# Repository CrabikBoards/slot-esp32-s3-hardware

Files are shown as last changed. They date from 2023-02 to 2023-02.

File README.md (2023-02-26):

# Crabik Slot ESP32-S3 Hardware

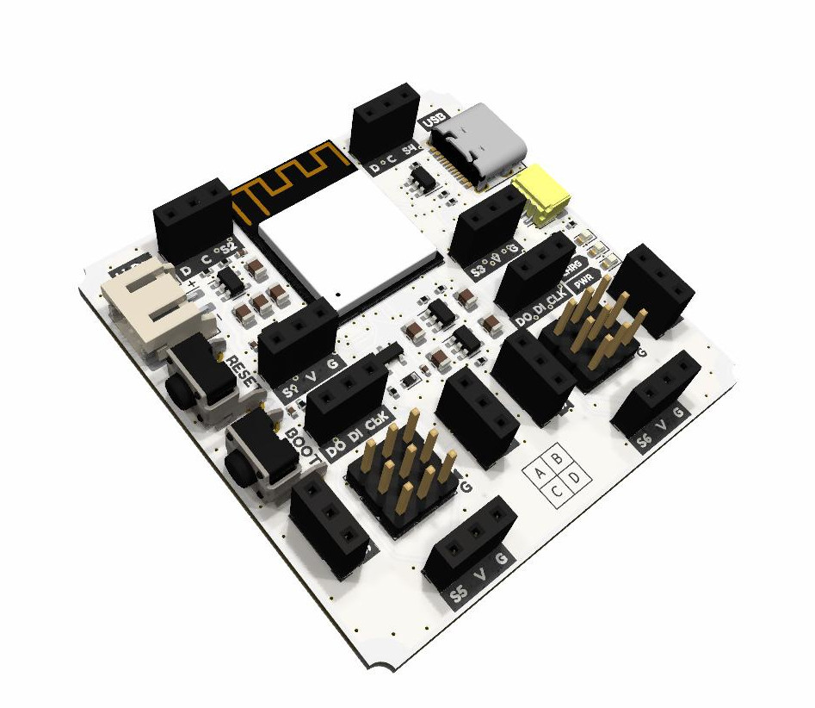
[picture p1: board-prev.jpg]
Board prev


Crabik Slot was created so that you can quickly prototype, research and educational projects, because it makes it easy to create and test without having to assemble everything on a breadboard and dig into a pile of wires.

Schematics and board designs (KiCad projects), distributed as open hardware and available under CERN-OHL-W v2 license.

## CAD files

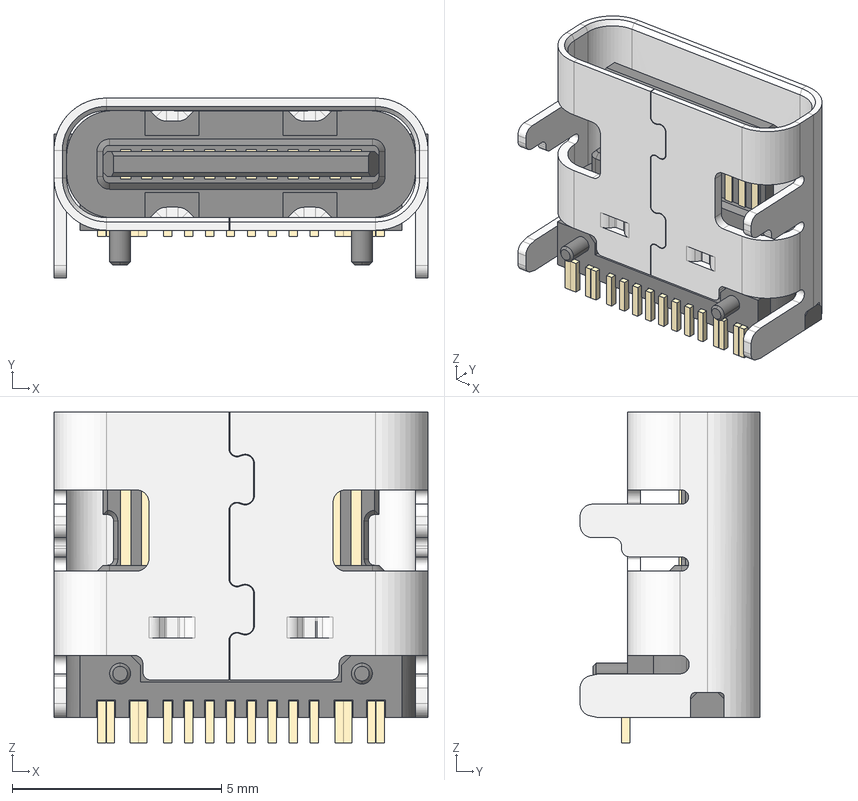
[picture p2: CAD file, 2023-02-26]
3d/TYPE-C-31-M-12.step
8.94 x 4.30 x 7.90 mm

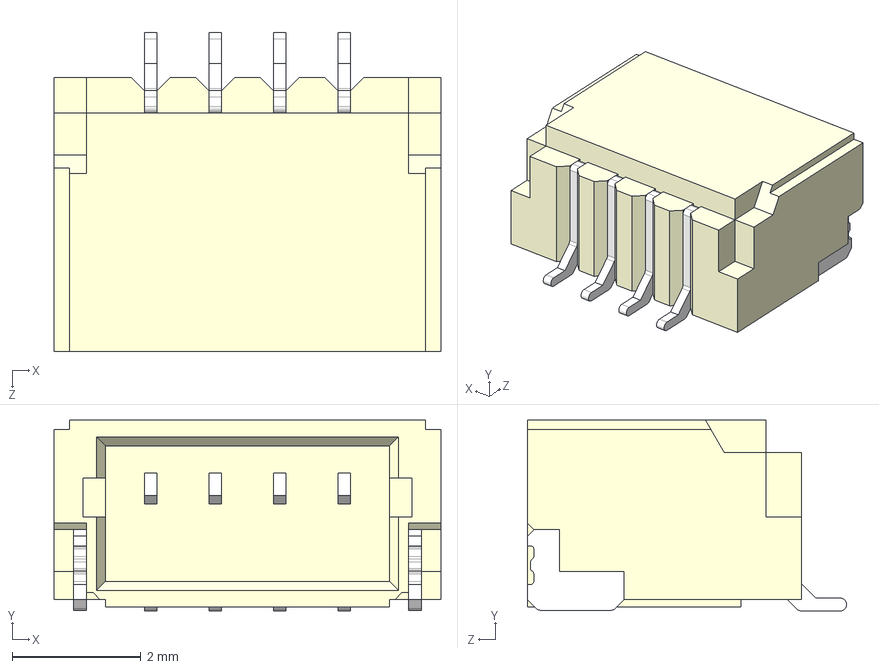
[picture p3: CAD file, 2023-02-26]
3d/JST_SH_SM04B-SRSS-TB_1x04-1MP_P1.00mm_Horizontal.STEP
6.00 x 2.96 x 4.95 mm

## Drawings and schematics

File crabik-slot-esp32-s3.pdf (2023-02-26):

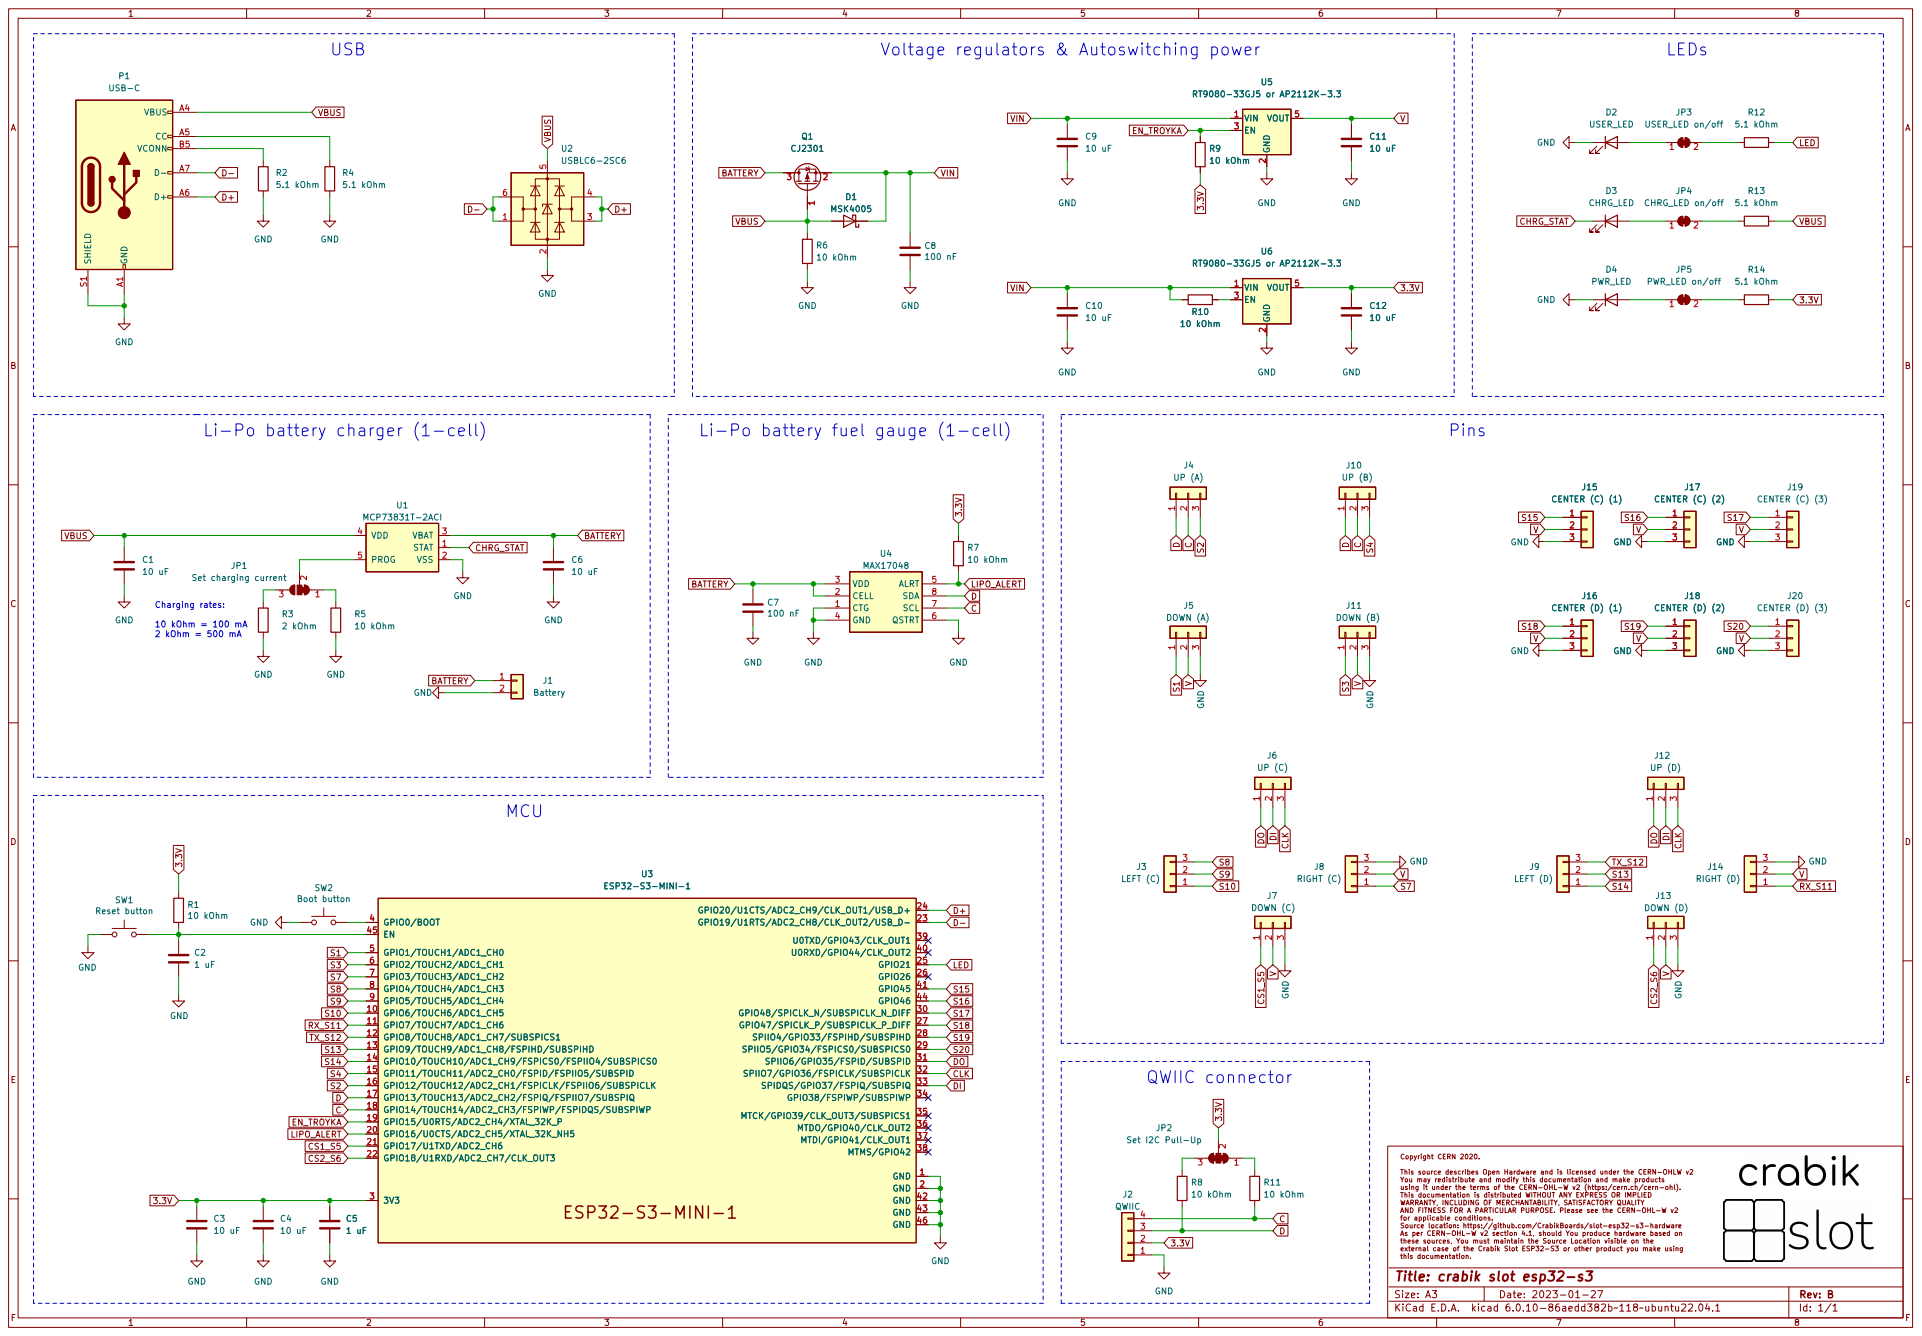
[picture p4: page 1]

Li-Po battery charger (1-cell)
10 uF GND

JP1 Set charging current GND GND

Charging rates: 10 kOhm = 100 mA

JP2 Set I2C Pull-Up GND

This source describes Open Hardware and is licensed under the CERN-OHLW v2

You may redistribute and modify this documentation and make products

using it under the terms of the CERN-OHL-W v2 (https:/cern.ch/cern-ohl).

Id: 1/1 Title: crabik slot esp32-s3

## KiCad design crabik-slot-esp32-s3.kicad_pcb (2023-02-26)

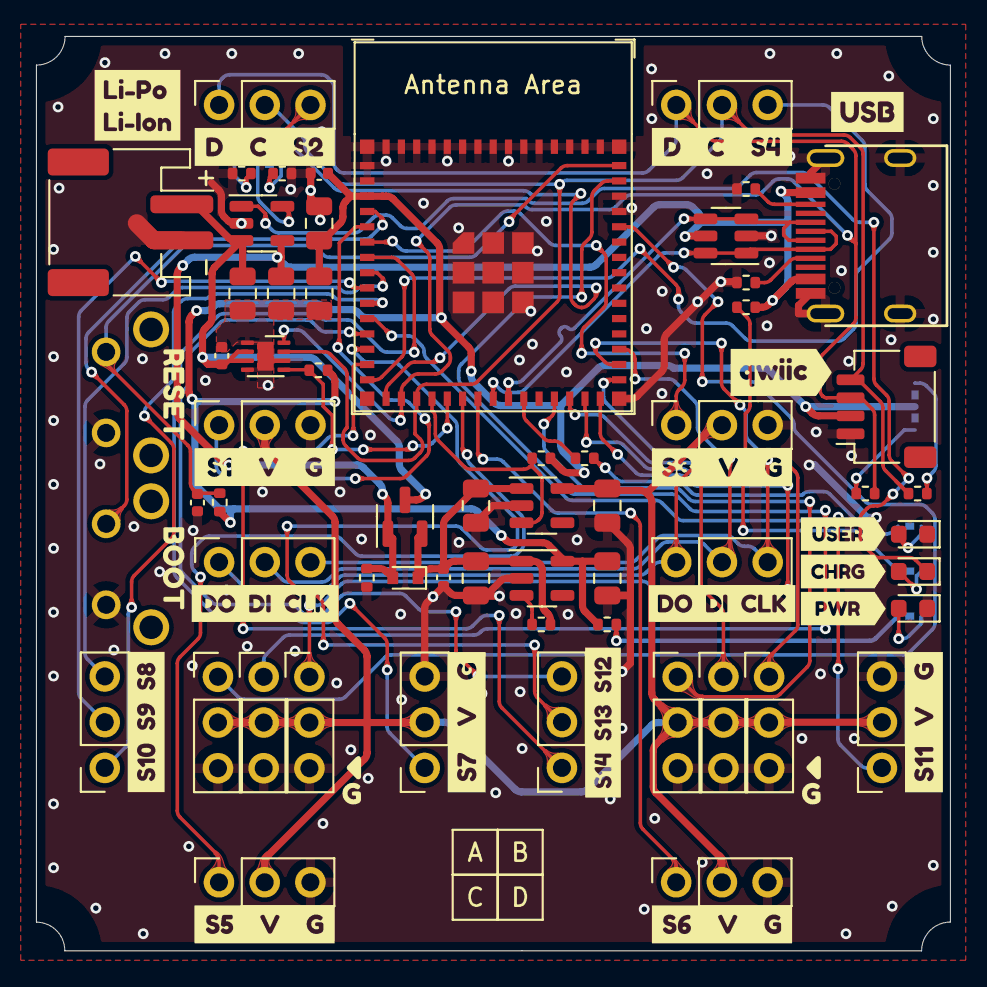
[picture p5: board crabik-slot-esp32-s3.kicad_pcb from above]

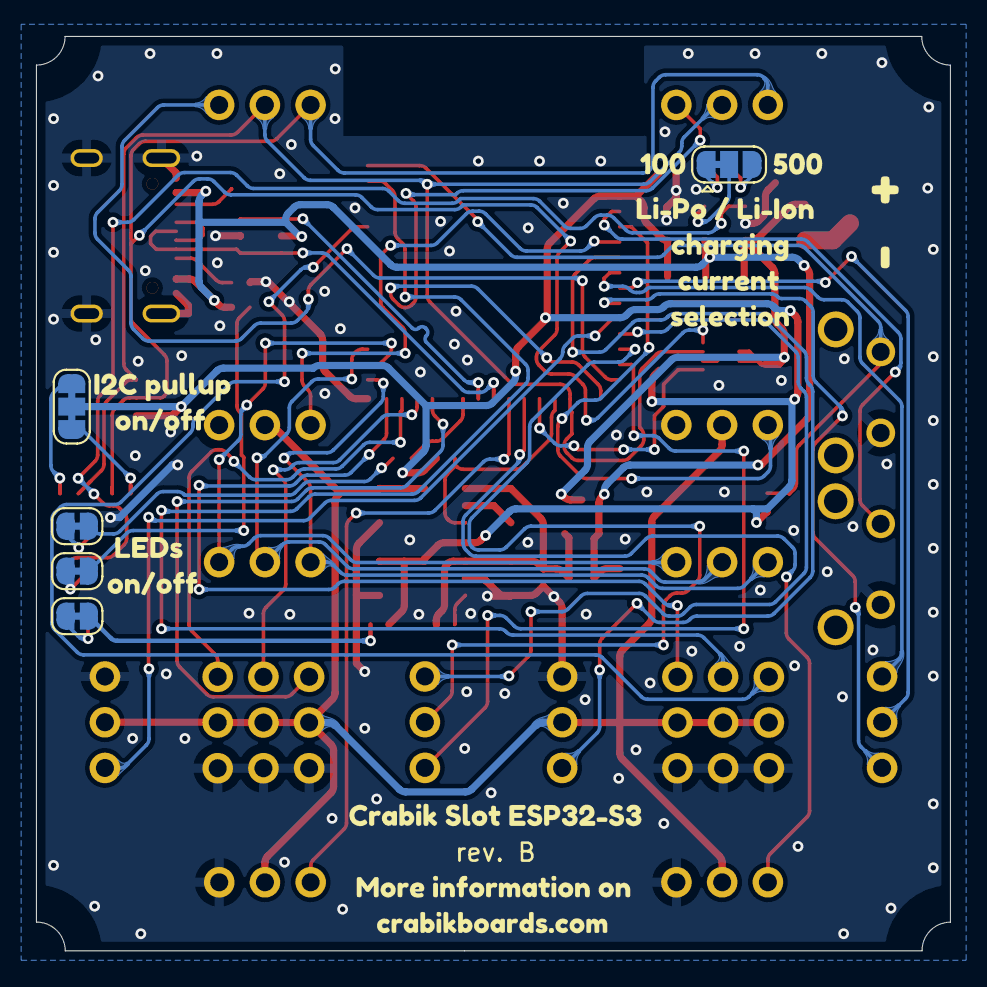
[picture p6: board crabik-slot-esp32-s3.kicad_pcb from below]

Board: 2 copper layers, 50.8 x 50.8 mm, 95 parts (13 on the bottom side), 53 nets.

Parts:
C1, C3, C4#2, C6, C9, C10, C11, C12: 10 uF; C_0805_2012Metric
C2, C5: 1 uF; C_0402_1005Metric
C4, C4#3: 100nF; C_0402_1005Metric
D1: MSK4005; D_SOD-523
D2: USER_LED; LED_0603_1608Metric
D3: CHRG_LED; LED_0603_1608Metric
D4: PWR_LED; LED_0603_1608Metric
J1, J1#2, J1#3, J1#4, J1#5, J1#7: UP (A); PinSocket_1x03_P2.54mm_Vertical
J1#6: Battery; JST_PH_S2B-PH-SM4-TB_1x02-1MP_P2.00mm_Horizontal
J2, J2#3: DOWN (A); PinSocket_1x03_P2.54mm_Vertical
J2#2: QWIIC; JST_SH_SM04B-SRSS-TB_1x04-1MP_P1.00mm_Horizontal
J4, J4#2: UP (B); PinSocket_1x03_P2.54mm_Vertical
J5, J5#2: DOWN (B); PinSocket_1x03_P2.54mm_Vertical
J15: CENTER (C) (1); PinHeader_1x03_P2.54mm_Vertical
J16: CENTER (D) (1); PinHeader_1x03_P2.54mm_Vertical
J17: CENTER (C) (2); PinHeader_1x03_P2.54mm_Vertical
J18: CENTER (D) (2); PinHeader_1x03_P2.54mm_Vertical
J19: CENTER (C) (3); PinHeader_1x03_P2.54mm_Vertical
J20: CENTER (D) (3); PinHeader_1x03_P2.54mm_Vertical
JP1: Set charging current; SolderJumper-3_P1.3mm_Bridged12_RoundedPad1.0x1.5mm
JP2: Set I2C Pull-Up; SolderJumper-3_P1.3mm_Bridged12_RoundedPad1.0x1.5mm_копия
JP3: USER_LED on/off; SolderJumper-2_P1.3mm_Bridged_RoundedPad1.0x1.5mm
JP4: CHRG_LED on/off; SolderJumper-2_P1.3mm_Bridged_RoundedPad1.0x1.5mm
JP5: PWR_LED on/off; SolderJumper-2_P1.3mm_Bridged_RoundedPad1.0x1.5mm
P1: USB-C; TYPE-C16PIN
Q1: CJ2301; SOT-23
R1: 10k; R_0402_1005Metric
R2, R4, R12, R13, R14: 5.1 kOhm; R_0402_1005Metric
R3: 2 kOhm; R_0402_1005Metric
R5, R6, R7, R8, R9, R10, R11: 10 kOhm; R_0402_1005Metric
SW1, SW1#2: Reset button; KEY-TH_4P-L7.1-W5.0-P4.50-LS2.5
U1: MCP73831T-2ACI; SOT-23-5
U2: USBLC6-2SC6; SOT-23-6
U3: ESP32-S3-MINI-1
U4: MAX17048; DFN-8-1EP_2x2mm_P0.5mm_EP0.9x1.6mm
U5, U6: RT9080-33GJ5 or AP2112K-3.3; SOT-23-5
kibuzzard-63C28F32: G***; kibuzzard-63C28F32
kibuzzard-63C28786: G***; kibuzzard-63C28786
kibuzzard-63C28790: G***; kibuzzard-63C28790
kibuzzard-63CA6CBF: G***; kibuzzard-63CA6CBF
kibuzzard-63CA6FA5: G***; kibuzzard-63CA6FA5
kibuzzard-63CE9BA7: G***; kibuzzard-63CE9BA7
kibuzzard-63CFAB7C: G***; kibuzzard-63CFAB7C
kibuzzard-63CFAB43: G***; kibuzzard-63CFAB43
kibuzzard-63CFACF8: G***; kibuzzard-63CFACF8
kibuzzard-63CFADAC: G***; kibuzzard-63CFADAC
kibuzzard-63CFAED5: G***; kibuzzard-63CFAED5
kibuzzard-63CFAF5C: G***; kibuzzard-63CFAF5C
kibuzzard-63CFAFAA: G***; kibuzzard-63CFAFAA
kibuzzard-63CFAFDE: G***; kibuzzard-63CFAFDE
kibuzzard-63CFB1DC: G***; kibuzzard-63CFB1DC
kibuzzard-63CFB14C, kibuzzard-63CFB14C#2: G***; kibuzzard-63CFB14C
kibuzzard-63CFB240: G***; kibuzzard-63CFB240
kibuzzard-63CFBBB1, kibuzzard-63CFBBB1#2: G***; kibuzzard-63CFBBB1
kibuzzard-637DF95D: G***; kibuzzard-637DF95D
kibuzzard-637DF950: G***; kibuzzard-637DF950
kibuzzard-637DF968: G***; kibuzzard-637DF968
kibuzzard-637F6C97: G***; kibuzzard-637F6C97
kibuzzard-637F6D25: G***; kibuzzard-637F6D25
kibuzzard-637F6DEA: G***; kibuzzard-637F6DEA
kibuzzard-637F6E06: G***; kibuzzard-637F6E06
kibuzzard-637F66BD: G***; kibuzzard-637F66BD
kibuzzard-637F708F: G***; kibuzzard-637F708F
kibuzzard-637F7041: G***; kibuzzard-637F7041

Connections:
3.3V: C3.1, C4#2.1, C5.1, C12.1, J2#2.2, JP2.2 (C), R1.1, R7.1, R9.2, R14.2, U3.3 (3V3), U6.5 (VOUT)
BATTERY: C4#3.1, C6.1, J1#6.1, Q1.3 (D), U1.3 (VBAT), U4.2 (CELL), U4.3 (VDD)
C: J1.2, J2#2.4, J4#2.2, R11.2, U3.18 (GPIO14/TOUCH14/ADC2_CH3/FSPIWP/FSPIDQS/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), U4.7 (SCL)
CHRG_STAT: D3.1 (K), U1.1 (STAT)
CLK: J1#4.3, J4.3, U3.32 (SPIIO7/GPIO36/FSPICLK/SUBSPICLK)
CS1_S5: J2#3.1, U3.21 (GPIO17/U1TXD/ADC2_CH6)
CS2_S6: J5#2.1, U3.22 (GPIO18/U1RXD/ADC2_CH7/CLK_OUT3)
D: J1.1, J2#2.3, J4#2.1, R8.2, U3.17 (GPIO13/TOUCH13/ADC2_CH2/FSPIQ/FSPIIO7/S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), U4.8 (SDA)
D+: P1.A6 (D+), U2.3 (I/O2), U2.4 (I/O2), U3.24 (GPIO20/U1CTS/ADC2_CH9/CLK_OUT1/USB_D+)
D-: P1.A7 (D-), U2.1 (I/O1), U2.6 (I/O1), U3.23 (GPIO19/U1RTS/ADC2_CH8/CLK_OUT2/USB_D-)
DI: J1#4.2, J4.2, U3.33 (SPIDQS/GPIO37/FSPIQ/SUBSPIQ)
DO: J1#4.1, J4.1, U3.31 (SPIIO6/GPIO35/FSPID/SUBSPID)
EN_TROYKA: R9.1, U3.19 (GPIO15/U0RTS/ADC2_CH4/XTAL_32K_P), U5.3 (EN)
GND: C1.2, C2.2, C3.2, C4.2, C4#2.2, C4#3.2, C5.2, C6.2, C9.2, C10.2, C11.2, C12.2, D2.1 (K), D4.1 (K), J1#2.3, J1#6.2, J1#7.3, J2.3, J2#2.1, J2#3.3, J5.3, J5#2.3, J15.3, J16.3, J17.3, J18.3, J19.3, J20.3, P1.A1 (GND), P1.S1 (SHIELD), R2.2, R3.2, R4.2, R5.2, R6.2, SW1.2, SW1#2.2, U1.2 (VSS), U2.2 (GND), U3.1 (GND), U3.2 (GND), U3.42 (GND), U3.43 (GND), U3.46 (GND), U4.1 (CTG), U4.4 (GND), U4.6 (QSTRT), U4.9 (GND), U5.2 (GND), U6.2 (GND)
LED: R12.2, U3.25 (GPIO21)
LIPO_ALERT: R7.2, U3.20 (GPIO16/U0CTS/ADC2_CH5/XTAL_32K_NH5), U4.5 (ALRT)
unnamed: C2.1, R1.2, SW1#2.1, U3.45 (EN)
unnamed: D2.2 (A), JP3.1 (A)
unnamed: D3.2 (A), JP4.1 (A)
unnamed: D4.2 (A), JP5.1 (A)
unnamed: JP1.1 (A), R5.1
unnamed: JP1.2 (C), U1.5 (PROG)
unnamed: JP1.3 (B), R3.1
unnamed: JP2.1 (A), R11.1
unnamed: JP2.3 (B), R8.1
unnamed: JP3.2 (B), R12.1
unnamed: JP4.2 (B), R13.1
unnamed: JP5.2 (B), R14.1
unnamed: P1.A5 (CC), R4.1
unnamed: P1.B5 (VCONN), R2.1
unnamed: R10.2, U6.3 (EN)
unnamed: SW1.1, U3.4 (GPIO0/BOOT)
RX_S11: J1#2.1, U3.11 (GPIO7/TOUCH7/ADC1_CH6)
S1: J2.1, U3.5 (GPIO1/TOUCH1/ADC1_CH0)
S2: J1.3, U3.16 (GPIO12/TOUCH12/ADC2_CH1/FSPICLK/FSPIIO6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)
S3: J5.1, U3.6 (GPIO2/TOUCH2/ADC1_CH1)
S4: J4#2.3, U3.15 (GPIO11/TOUCH11/ADC2_CH0/FSPID/FSPIIO5/S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)
S7: J1#7.1, U3.7 (GPIO3/TOUCH3/ADC1_CH2)
S8: J1#3.3, U3.8 (GPIO4/TOUCH4/ADC1_CH3)
S9: J1#3.2, U3.9 (GPIO5/TOUCH5/ADC1_CH4)
S10: J1#3.1, U3.10 (GPIO6/TOUCH6/ADC1_CH5)
S13: J1#5.2, U3.13 (GPIO9/TOUCH9/ADC1_CH8/FSPIHD/SUBSPIHD)
S14: J1#5.1, U3.14 (GPIO10/TOUCH10/ADC1_CH9/FSPICS0/FSPIIO4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)
S15: J15.1, U3.41 (GPIO45)
S16: J17.1, U3.44 (GPIO46)
S17: J19.1, U3.30 (GPIO48/SPICLK_N/SUBSPICLK_N_DIFF)
S18: J16.1, U3.27 (GPIO47/SPICLK_P/SUBSPICLK_P_DIFF)
S19: J18.1, U3.28 (SPIIO4/GPIO33/FSPIHD/SUBSPIHD)
S20: J20.1, U3.29 (SPIIO5/GPIO34/FSPICS0/SUBSPICS0)
TX_S12: J1#5.3, U3.12 (GPIO8/TOUCH8/ADC1_CH7/SUBSPICS1)
V: C11.1, J1#2.2, J1#7.2, J2.2, J2#3.2, J5.2, J5#2.2, J15.2, J16.2, J17.2, J18.2, J19.2, J20.2, U5.5 (VOUT)
VBUS: C1.1, D1.2 (A), P1.A4 (VBUS), Q1.1 (G), R6.1, R13.2, U1.4 (VDD), U2.5 (VBUS)
VIN: C4.1, C9.1, C10.1, D1.1 (K), Q1.2 (S), R10.1, U5.1 (VIN), U6.1 (VIN)
